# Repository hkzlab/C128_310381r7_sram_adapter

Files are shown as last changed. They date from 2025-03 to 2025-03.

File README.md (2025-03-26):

# C128 310381 R7 SRAM Adapter

## DISCLAIMER

Any use of this project is **under your own responsibility**.
You will be responsible of checking the correct construction and functionality of your board.
By using this project You will agree that I cannot be held responsible if it will destroy any of your devices, damage your computer, burn down your house or whatever.

**WARNING**: This device was only tested to fit on a motherboard model 310381R7!!!

**ANOTHER WARNING**: This device is still under testing, and while it seems to be working without issues on my C128, there are no guarantees!

## Introduction

This board implements a static RAM replacement for the DRAMs on a C128 with a 310381R7 motherboard.

You will have to remove and socket your DRAM ICs to install this board. Please, do not kill innocent DRAM ICs by cutting their legs!

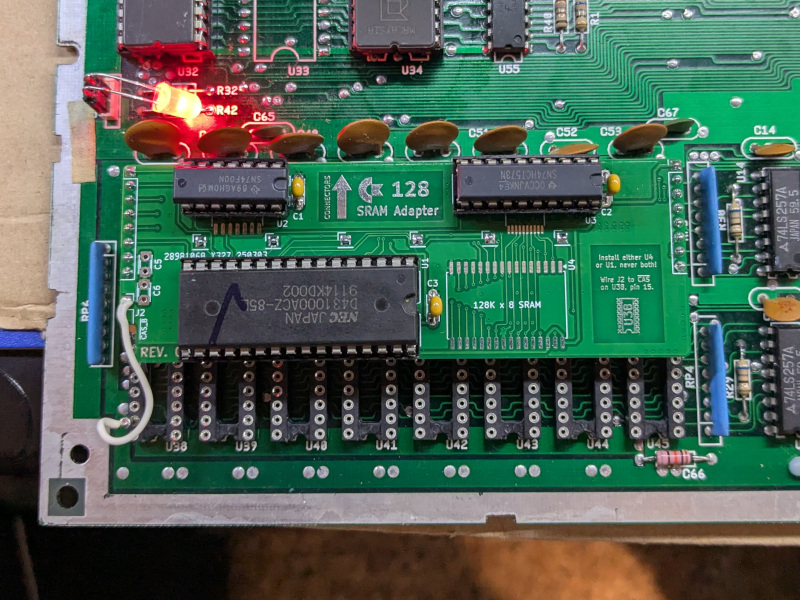
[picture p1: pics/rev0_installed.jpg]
Rev. 0 board installed in a C128


### Ordering the boards

You can order the board for this project at [PCBWay](https://www.pcbway.com/project/shareproject/Commodore_C128_310381_R7_SRAM_Adapter_aeccc292.html) and support me or download 
the gerbers and have them printed wherever you like!!!

## Features

- You can choose to use SMD or DIP components
- Once the DRAMs are socketed, the board is easy to plug in and remove

## Hardware

The board was designed with [KiCad](https://kicad.org/) EDA.

### Bill of Materials

| Component | Qty | Type / Value | Notes |
| --- | --- | --- | --- |
| C1, C2, C3 |  3  | 100nF ceramic cap, SMD 1206 or 2.54mm through hole | Decoupling caps, rated at least 10V. |
| C5, C6 |  2  | ~82-820pF ceramic cap, 1206 or THT 2.54mm | Optional tweak on CAS timing, normally no need to fit this |
| U1, U4 |  1  | 128Kx8 SRAM, DIP32 or SOP32 | I tested 85ns SRAMs without issue. 628128 pinout. Install either U1 or U4. |
| U2 |  1  | 74HCT00, DIP14 or SO14 | Can be replaced with an ACT/ALS/LS/F. Do NOT use an HC. Note: F/LS/ACT/HCT currently tested |
| U3 |  1  | 74HCT573, DIP 20 or TSSOP20 | Can be replaced with an ACT/ALS/LS/F. Do NOT use an HC. Note: Only HCT currently tested |
| J2 |  1  | Angled header or wire | Install an angled header or a wire that goes to the second CAS line, U38 pin 15 |
| Headers |  1  | 40p 2.54mm machined header strip | Cut it into 4x8p and 6x1p pieces, then solder on the underside |

### Known Issues

I could not detect stability issues. Yet.

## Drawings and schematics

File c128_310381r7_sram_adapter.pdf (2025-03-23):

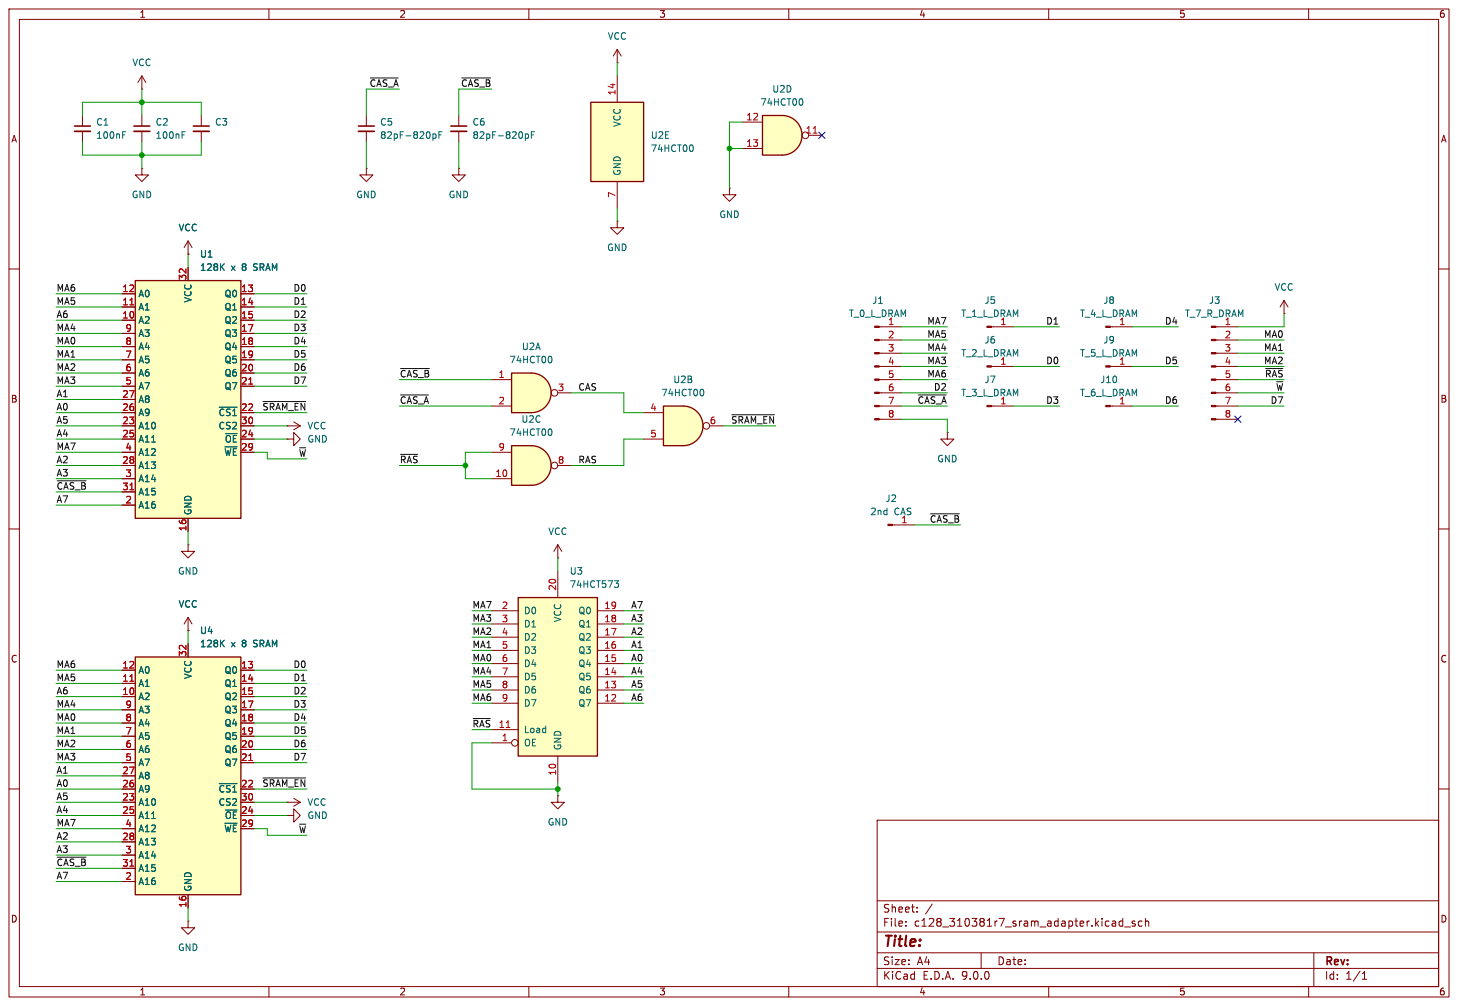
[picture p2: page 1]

Id: 1/1 Title: File: c128_310381r7_sram_adapter.kicad_sch Sheet: /

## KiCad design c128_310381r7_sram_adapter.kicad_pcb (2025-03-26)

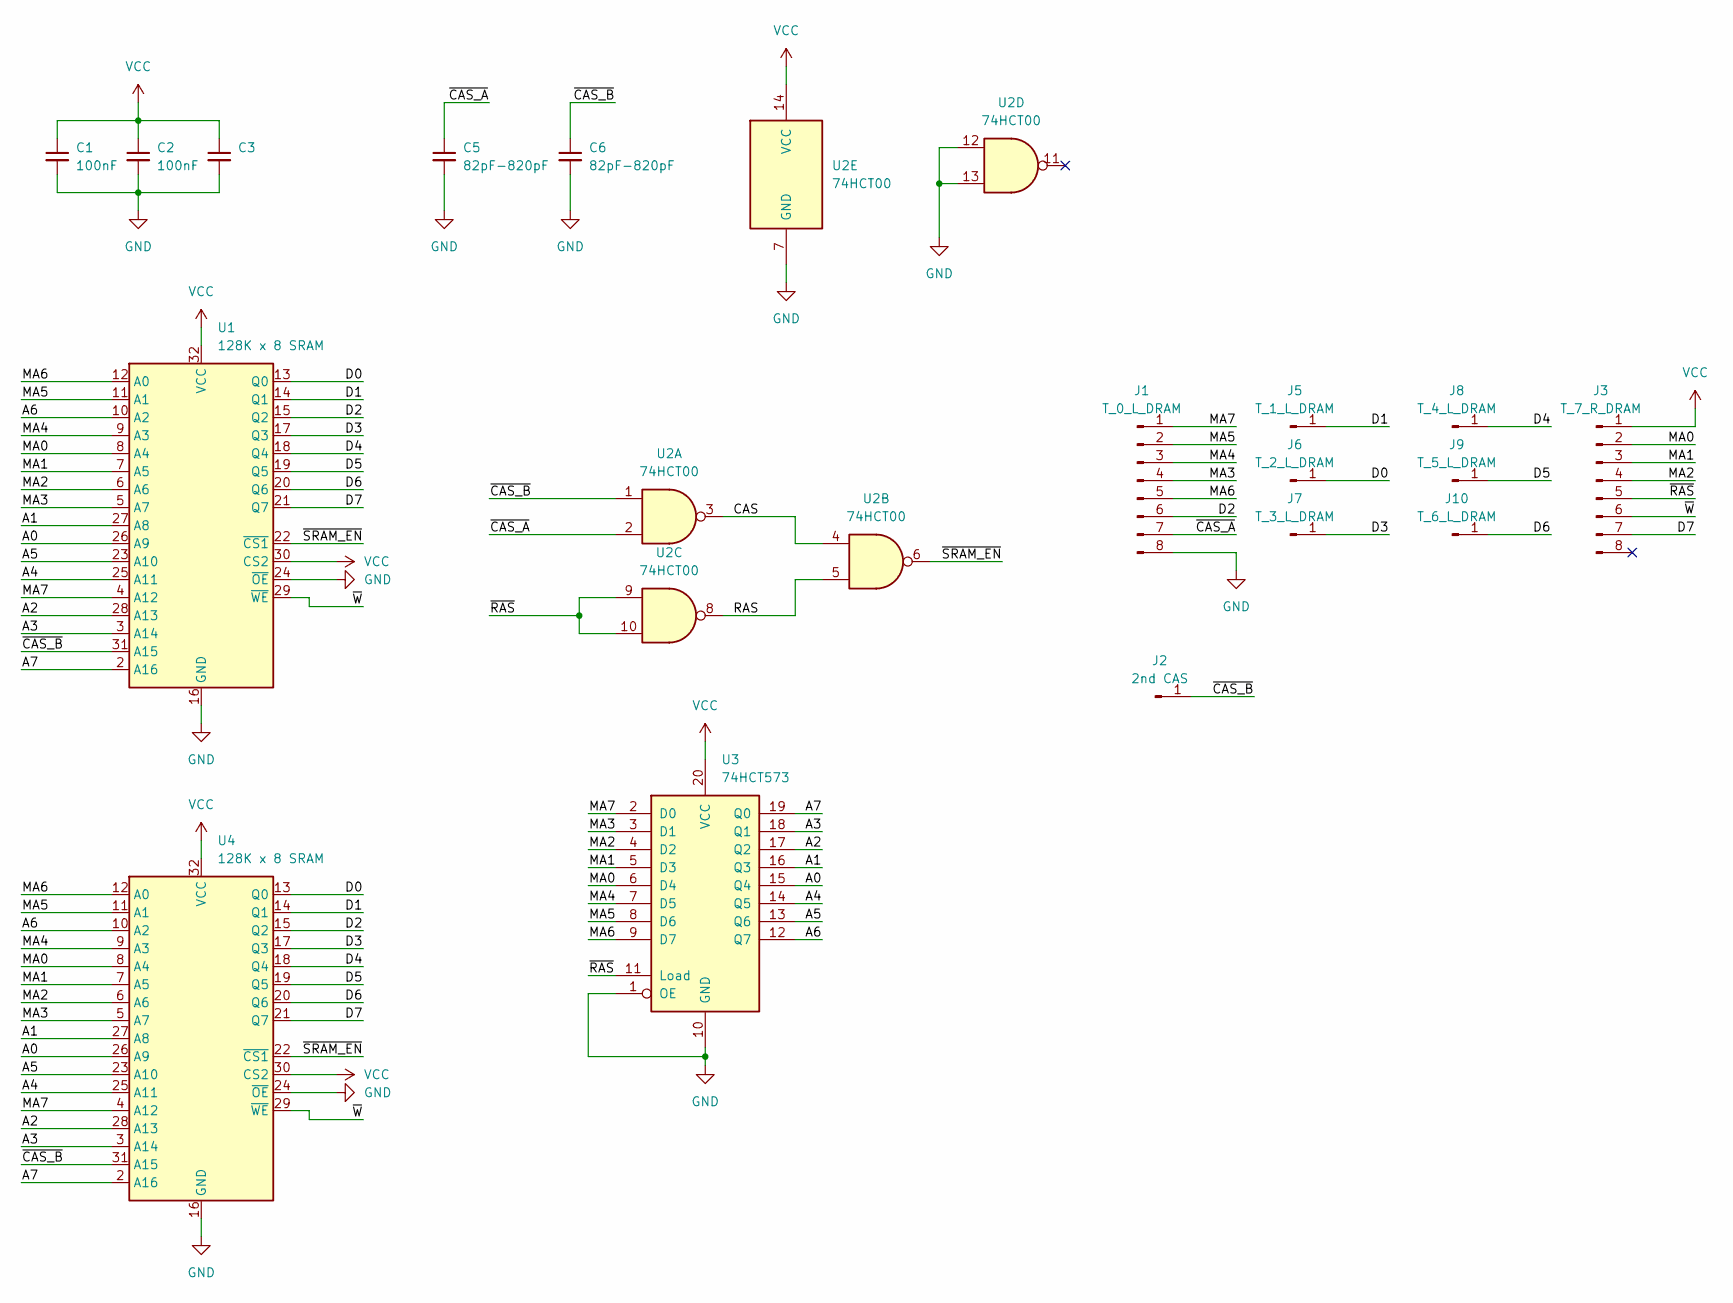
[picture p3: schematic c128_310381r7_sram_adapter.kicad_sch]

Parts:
C1, C2, C3: 100nF; C_Disc_1206_P5.00mm
C5, C6: 82pF-820pF; C_Disc_1206_P2.50mm
J1: T_0_L_DRAM; PinHeader_1x08_P2.54mm_Vertical
J2: 2nd CAS; PinHeader_1x01_P2.54mm_Horizontal
J3: T_7_R_DRAM; PinHeader_1x08_P2.54mm_Vertical
J5: T_1_L_DRAM; PinHeader_1x01_P2.54mm_Vertical
J6: T_2_L_DRAM; PinHeader_1x01_P2.54mm_Vertical
J7: T_3_L_DRAM; PinHeader_1x01_P2.54mm_Vertical
J8: T_4_L_DRAM; PinHeader_1x01_P2.54mm_Vertical
J9: T_5_L_DRAM; PinHeader_1x01_P2.54mm_Vertical
J10: T_6_L_DRAM; PinHeader_1x01_P2.54mm_Vertical
U1: 128K x 8 SRAM; DIP-32_W15.24mm
U2: 74HCT00; DIP-SO-14
U3: 74HCT573; DIP-TSSOP-20
U4: 128K x 8 SRAM; SOP-32_11.305x20.495mm_P1.27mm

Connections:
/A0: U1.26 (A9), U3.15 (Q4), U4.26 (A9)
/A1: U1.27 (A8), U3.16 (Q3), U4.27 (A8)
/A2: U1.28 (A13), U3.17 (Q2), U4.28 (A13)
/A3: U1.3 (A14), U3.18 (Q1), U4.3 (A14)
/A4: U1.25 (A11), U3.14 (Q5), U4.25 (A11)
/A5: U1.23 (A10), U3.13 (Q6), U4.23 (A10)
/A6: U1.10 (A2), U3.12 (Q7), U4.10 (A2)
/A7: U1.2 (A16), U3.19 (Q0), U4.2 (A16)
/CAS: U2.3, U2.4
/D0: J6.1, U1.13 (Q0), U4.13 (Q0)
/D1: J5.1, U1.14 (Q1), U4.14 (Q1)
/D2: J1.6, U1.15 (Q2), U4.15 (Q2)
/D3: J7.1, U1.17 (Q3), U4.17 (Q3)
/D4: J8.1, U1.18 (Q4), U4.18 (Q4)
/D5: J9.1, U1.19 (Q5), U4.19 (Q5)
/D6: J10.1, U1.20 (Q6), U4.20 (Q6)
/D7: J3.7, U1.21 (Q7), U4.21 (Q7)
/MA0: J3.2, U1.8 (A4), U3.6 (D4), U4.8 (A4)
/MA1: J3.3, U1.7 (A5), U3.5 (D3), U4.7 (A5)
/MA2: J3.4, U1.6 (A6), U3.4 (D2), U4.6 (A6)
/MA3: J1.4, U1.5 (A7), U3.3 (D1), U4.5 (A7)
/MA4: J1.3, U1.9 (A3), U3.7 (D5), U4.9 (A3)
/MA5: J1.2, U1.11 (A1), U3.8 (D6), U4.11 (A1)
/MA6: J1.5, U1.12 (A0), U3.9 (D7), U4.12 (A0)
/MA7: J1.1, U1.4 (A12), U3.2 (D0), U4.4 (A12)
/RAS: U2.5, U2.8
/~CAS_A: C5.1, J1.7, U2.2
/~CAS_B: C6.1, J2.1, U1.31 (A15), U2.1, U4.31 (A15)
/~RAS: J3.5, U2.9, U2.10, U3.11 (Load)
/~SRAM_EN: U1.22 (~CS1), U2.6, U4.22 (~CS1)
/~W: J3.6, U1.29 (~WE), U4.29 (~WE)
GND: C1.2, C2.2, C3.2, C5.2, C6.2, J1.8, U1.16 (GND), U1.24 (~OE), U2.7 (GND), U2.12, U2.13, U3.1 (OE), U3.10 (GND), U4.16 (GND), U4.24 (~OE)
VCC: C1.1, C2.1, C3.1, J3.1, U1.30 (CS2), U1.32 (VCC), U2.14 (VCC), U3.20 (VCC), U4.30 (CS2), U4.32 (VCC)

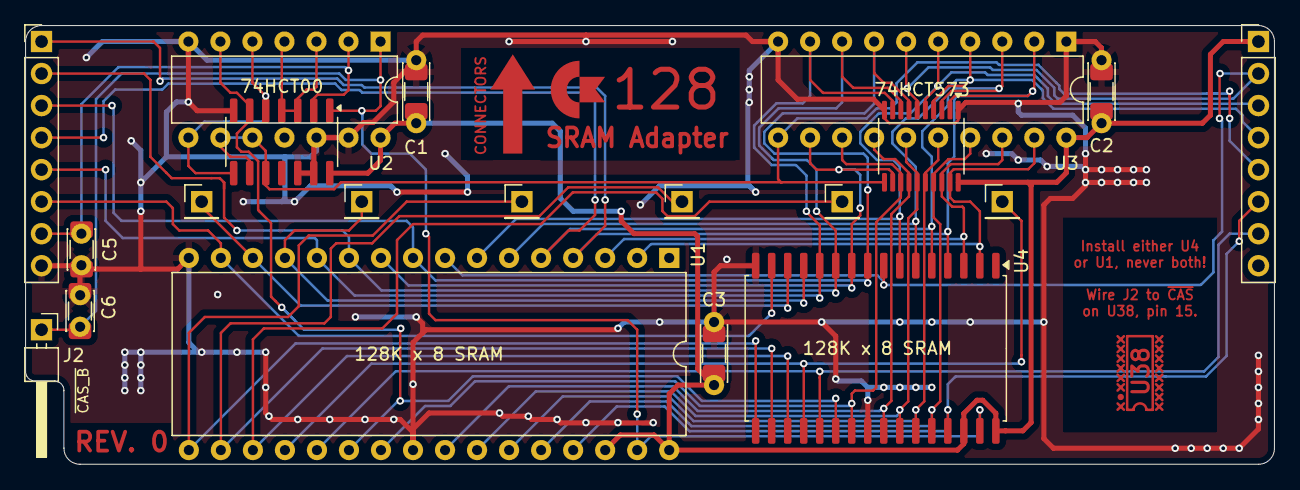
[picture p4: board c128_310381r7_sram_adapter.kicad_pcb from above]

Board: 2 copper layers, 99.1 x 34.8 mm, 18 parts (0 on the bottom side), 33 nets.

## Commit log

2025-02-08 Initial schematic for the SRAM adapter
    [c128_310381r7_sram_adapter.kicad_pcb, c128_310381r7_sram_adapter.kicad_sch]
2025-02-08 Schematic for the connections of the SRAM adapter
    [c128_310381r7_sram_adapter.kicad_sch]
2025-02-09 Wire A15 to /CAS_A signal
    [c128_310381r7_sram_adapter.kicad_sch]
2025-02-09 Add custom footprints for components in this adapter
    [c128_310381r7_sram_adapter.kicad_pcb, c128_310381r7_sram_adapter.kicad_sch]
2025-02-09 Begin drawing traces
    [c128_310381r7_sram_adapter.kicad_pcb, c128_310381r7_sram_adapter.kicad_sch]
2025-02-09 Complete routing of first revision of the adapter
    [c128_310381r7_sram_adapter.kicad_pcb, c128_310381r7_sram_adapter.kicad_sch]
2025-02-10 Update silkscreen and drawings on the PCB
    [c128_310381r7_sram_adapter.kicad_pcb]
2025-03-02 Add rev_0 gerbers
2025-03-23 Update the README
    [c128_310381r7_sram_adapter.kicad_sch]
2025-03-23 Update README to include link to PCBway project page
2025-03-26 Update project files with new kicad version
    [c128_310381r7_sram_adapter.kicad_pcb]
